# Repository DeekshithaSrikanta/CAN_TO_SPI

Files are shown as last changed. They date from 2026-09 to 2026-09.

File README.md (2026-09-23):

CAN to SPI Bridge (FPGA RTL)

 Overview

This repository contains a Verilog-based RTL architecture that bridges a Controller Area Network (CAN) bus to a Serial Peripheral Interface (SPI).
Designed and tested on the Intel DE10-Lite (MAX 10 - 10M50DAF484C7G) FPGA, this system ingests a 500 kbps serial CAN frame, validates the data (CRC and EOF), packages the identifier and payload into a 112-bit parallel register, and transmits it serially via an SPI Master interface.

System Architecture and Data Flow

The bridge operates through three distinct hardware phases:

1. CAN Frame Ingestion: The `can_controller` state machine parses the incoming serial CAN bitstream (500 kbps) via the `can_rx` pin. It actively calculates the CRC-15 and handles bit-stuffing logic.
2.Parallel Assembly: Upon successful End of Frame (EOF) validation, the parsed CAN ID, Data Length Code (DLC), and payload are packaged into a single 112-bit internal parallel register (`spi_rx_packet`).
3. SPI Transmission: Once the parallel packet is assembled, the SPI master activates the Chip Select (`cs_n`), pulses the SPI Clock (`sck`), and shifts the 112-bit payload out serially over the `mosi` pin.

## Module Breakdown

* `can_spi_master_top.v` - The top-level wrapper that connects the physical FPGA pins to the internal bridge logic.
* `can_controller.v` - The FSM that handles the CAN protocol parsing, idle state detection, CRC validation, and EOF checking.
* `can_generator.v` - An internal hardware bypass module. It acts as an on-chip test pattern generator that injects a pre-recorded, perfectly timed CAN frame directly into the controller, triggered by a physical slide switch.

Hardware Requirements

* Board: Terasic DE10-Lite (Intel MAX 10 FPGA)
* Target Device: 10M50DAF484C7G
* Clock: 50 MHz internal oscillator

Pin Assignments (DE10-Lite)

| Signal Name | FPGA Pin | Board Component / I/O Standard |
| --- | --- | --- |
| `clk_50mhz` | `PIN_P11` | 50 MHz MAX 10 Clock (3.3-V LVTTL) |
| `rst_n` | `PIN_B8` | KEY[0] Push Button (3.3-V LVTTL) |
| `can_rx` | `PIN_V10` | GPIO Expansion Header (3.3-V LVTTL) |
| `mosi` | `PIN_V9` | GPIO Expansion Header (3.3-V LVTTL) |
| `cs_n` | `PIN_W9` | GPIO Expansion Header (3.3-V LVTTL) |
| `sck` | `PIN_W10` | GPIO Expansion Header (3.3-V LVTTL) |
| `test_switch` | `PIN_C10` | SW[0] Slide Switch (Internal test trigger) |

 Simulation and Verification

This project has been verified using both RTL Simulation (for mathematical and state machine validation) and
Gate-Level Simulation (GLS) (for physical timing, synthesis mapping, and propagation delay validation).

2. Open Signal Tap and set the trigger to `cs_n` (Falling Edge).
3. Flick `SW[0]` on the board to activate the `can_generator.v` module.
4. The internal generator will feed a simulated 500 kbps CAN frame to the controller, allowing Signal Tap to capture the resulting SPI output on `mosi` and `sck`.

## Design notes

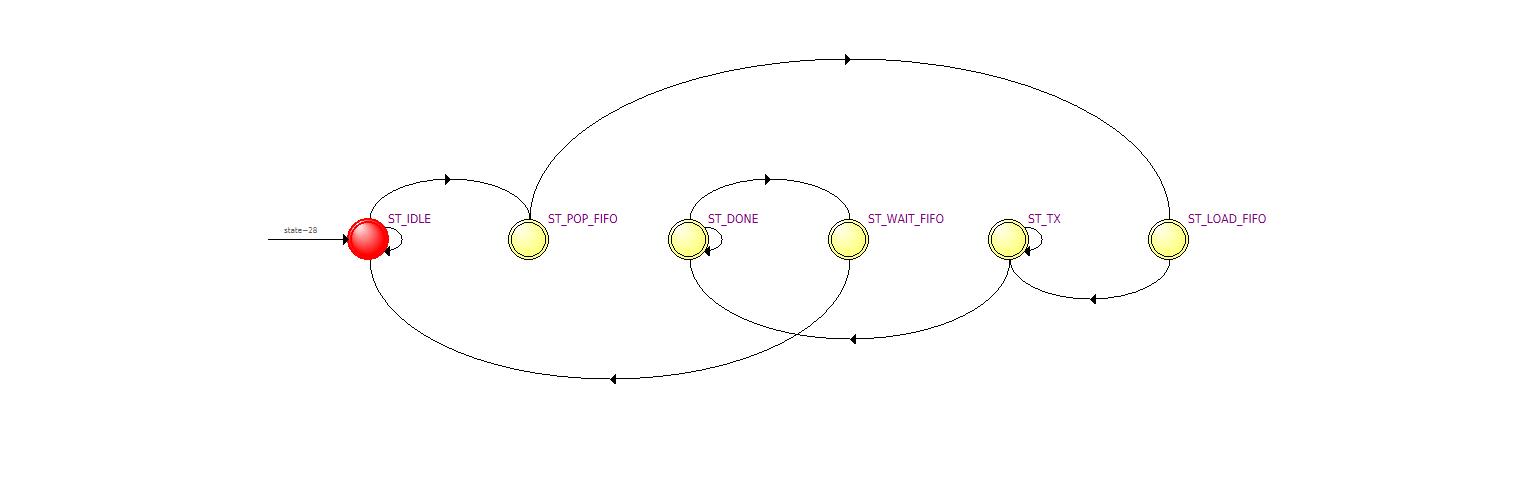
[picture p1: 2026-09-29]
state diagram.jpg

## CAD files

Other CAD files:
stp1.stp

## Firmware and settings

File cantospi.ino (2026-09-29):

#include <Arduino.h>
#include <string.h>
#include "driver/spi_slave.h"
#include "driver/spi_common.h"
#include "driver/twai.h"

// ---------- Active Pins ----------
#define CAN_TX_PIN GPIO_NUM_5
#define SPI_MOSI 13
#define SPI_SCLK 14
#define SPI_CS   15

// FPGA outputs a 112-bit packet (14 bytes)
#define SPI_PACKET_SIZE 14
WORD_ALIGNED_ATTR uint8_t spi_rx_buf[SPI_PACKET_SIZE];

void setup() {
  Serial.begin(115200);
  delay(1000);

  Serial.println("\nESP32 CAN Transmit + SPI Slave Test");

  // 1. Configure SPI Slave (Receive Only)
  spi_bus_config_t buscfg;
  memset(&buscfg, 0, sizeof(buscfg));
  buscfg.mosi_io_num = SPI_MOSI;
  buscfg.miso_io_num = -1;       // Completely disabled
  buscfg.sclk_io_num = SPI_SCLK;
  buscfg.quadwp_io_num = -1;
  buscfg.quadhd_io_num = -1;
  buscfg.max_transfer_sz = 32;

  spi_slave_interface_config_t slvcfg;
  memset(&slvcfg, 0, sizeof(slvcfg));
  slvcfg.spics_io_num = SPI_CS;
  slvcfg.queue_size = 1;
  slvcfg.mode = 0; 

  spi_slave_initialize(VSPI_HOST, &buscfg, &slvcfg, SPI_DMA_CH_AUTO);
  Serial.println("SPI Slave initialized on Pins 13, 14, 15.");

  // 2. Configure CAN (TWAI)
  twai_general_config_t g_config = TWAI_GENERAL_CONFIG_DEFAULT(CAN_TX_PIN, GPIO_NUM_4, TWAI_MODE_NO_ACK);
  twai_timing_config_t t_config = TWAI_TIMING_CONFIG_500KBITS();
  twai_filter_config_t f_config = TWAI_FILTER_CONFIG_ACCEPT_ALL();

  twai_driver_install(&g_config, &t_config, &f_config);
  twai_start();
  Serial.println("CAN Driver initialized on Pin 5.");

  Serial.println("\nType 's' in the serial monitor and press Enter to start.");
}

void loop() {
  if (Serial.available() > 0) {
    char incoming = Serial.read();
    if (incoming == 's' || incoming == 'S') {
      
      // A. Queue the SPI listener FIRST
      spi_slave_transaction_t t;
      memset(&t, 0, sizeof(t));
      t.length = SPI_PACKET_SIZE * 8; 
      t.rx_buffer = spi_rx_buf;
      t.tx_buffer = NULL; // Explicitly disabled
      
      spi_slave_queue_trans(VSPI_HOST, &t, portMAX_DELAY);

      // B. Transmit the CAN Frame
      twai_message_t message;
      message.identifier = 0x123;
      message.extd = 0;
      message.data_length_code = 8;
      uint8_t payload[8] = {0x11, 0x22, 0x33, 0x44, 0x55, 0x66, 0x77, 0x88};
      memcpy(message.data, payload, 8);

      if (twai_transmit(&message, pdMS_TO_TICKS(1000)) == ESP_OK) {
        Serial.println("\n-> CAN Sent (ID: 0x123). Waiting for SPI reply...");
      }

      // C. Wait for the SPI transaction from the FPGA to complete (2-second timeout)
      spi_slave_transaction_t *completed = nullptr;
      esp_err_t result = spi_slave_get_trans_result(VSPI_HOST, &completed, pdMS_TO_TICKS(2000));

      if (result == ESP_OK) {
        Serial.print("<- SUCCESS: Received 14 bytes from FPGA: ");
        for (int i = 0; i < SPI_PACKET_SIZE; i++) {
          Serial.printf("%02X ", spi_rx_buf[i]);
        }
        Serial.println();
        
        if (spi_rx_buf[0] == 0xAA && spi_rx_buf[12] == 0x55 && spi_rx_buf[13] == 0x55) {
          Serial.println("<- VERIFIED: Packet headers and footers match perfectly!");
        }
      } else {
        Serial.printf("<- ERROR: SPI Receive Timed Out (Code: %d).\n", result);
      }
    }
  }
}

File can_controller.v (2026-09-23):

`timescale 1ns / 1ps

module can_controller (
    input  wire        clk_50mhz,
    input  wire        rst_n,
    input  wire        rxd,
    
    output reg         frame_valid,
    output reg  [10:0] id,
    output reg  [3:0]  dlc,
    output wire [63:0] data,
    output reg         frame_error
);

    // -------------------------------------------------------------------------
    // State Machine Parameters (Moved to top for global scope visibility)
    // -------------------------------------------------------------------------
    localparam ST_IDLE      = 4'd0;
    localparam ST_ID        = 4'd1;
    localparam ST_RTR       = 4'd2;
    localparam ST_IDE       = 4'd3;
    localparam ST_R0        = 4'd4;
    localparam ST_DLC       = 4'd5;
    localparam ST_DATA      = 4'd6;
    localparam ST_CRC       = 4'd7;
    localparam ST_CRC_DELIM = 4'd8;
    localparam ST_EOF_WAIT  = 4'd9;

    reg [3:0] state;

    // -------------------------------------------------------------------------
    // 1. Bit Timing Unit (Synchronization & Oversampling)
    // -------------------------------------------------------------------------
    reg rxd_sync1, rxd_sync2, rxd_sync2_d;
    always @(posedge clk_50mhz or negedge rst_n) begin
        if (!rst_n) begin
            rxd_sync1   <= 1'b1;
            rxd_sync2   <= 1'b1;
            rxd_sync2_d <= 1'b1;
        end else begin
            rxd_sync1   <= rxd;
            rxd_sync2   <= rxd_sync1;
            rxd_sync2_d <= rxd_sync2;
        end
    end
    
    wire falling_edge = !rxd_sync2 && rxd_sync2_d;
    reg [2:0] prescaler;
    reg [4:0] tq_count;
    
    wire tq_tick = (prescaler == 3'd4);
    wire sample_enable = (tq_tick && tq_count == 5'd15); 
    
    // Updated to use the clean parameter name
    wire is_idle = (state == ST_IDLE); 
    
    always @(posedge clk_50mhz or negedge rst_n) begin
        if (!rst_n) begin
            prescaler <= 3'd0;
            tq_count  <= 5'd1;
        end else begin
            if (falling_edge && is_idle) begin 
                prescaler <= 3'd0;
                tq_count  <= 5'd1;
            end else if (tq_tick) begin
                prescaler <= 3'd0;
                if (tq_count == 5'd20) tq_count <= 5'd1;
                else tq_count <= tq_count + 5'd1;
            end else begin
                prescaler <= prescaler + 3'd1;
            end
        end
    end

    // -------------------------------------------------------------------------
    // 2. Destuffer
    // -------------------------------------------------------------------------
    reg [2:0] consec_cnt;
    reg       prev_bit;
    reg       destuffed_bit;
    reg       valid_bit_en;
    reg       stuff_err_flag;
    
    // Destuffing active from ST_ID to ST_CRC
    wire destuff_en = (state >= ST_ID && state <= ST_CRC); 

    always @(posedge clk_50mhz or negedge rst_n) begin
        if (!rst_n) begin
            consec_cnt     <= 3'd1;
            prev_bit       <= 1'b1;
            valid_bit_en   <= 1'b0;
            stuff_err_flag <= 1'b0;
            destuffed_bit  <= 1'b1;
        end else begin
            valid_bit_en   <= 1'b0;
            stuff_err_flag <= 1'b0;

            if (sample_enable) begin
                if (!destuff_en) begin
                    consec_cnt    <= 3'd1;
                    prev_bit      <= rxd_sync2;
                    destuffed_bit <= rxd_sync2;
                    valid_bit_en  <= 1'b1;
                end else begin
                    if (consec_cnt == 3'd5) begin
                        if (rxd_sync2 == prev_bit) stuff_err_flag <= 1'b1;
                        consec_cnt <= 3'd1;
                        prev_bit   <= rxd_sync2;
                    end else begin
                        if (rxd_sync2 == prev_bit) consec_cnt <= consec_cnt + 3'd1;
                        else consec_cnt <= 3'd1;
                        
                        prev_bit      <= rxd_sync2;
                        destuffed_bit <= rxd_sync2;
                        valid_bit_en  <= 1'b1;
                    end
                end
            end
        end
    end

    // -------------------------------------------------------------------------
    // 3. CRC-15 LFSR (Polynomial: x^15 + x^14 + x^10 + x^8 + x^7 + x^4 + x^3 + 1)
    // -------------------------------------------------------------------------
    reg [14:0] calc_crc;
    reg [14:0] rx_crc;
    
    // CRC accumulates from ST_ID through ST_DATA
    wire crc_enable = (state >= ST_ID && state <= ST_DATA); 
    
    wire crc_feedback = calc_crc[14] ^ destuffed_bit;
    wire [14:0] next_crc = {calc_crc[13:0], 1'b0} ^ (crc_feedback ? 15'h4599 : 15'h0000);

    always @(posedge clk_50mhz or negedge rst_n) begin
        if (!rst_n) calc_crc <= 15'd0;
        else if (valid_bit_en) begin
            if (state == ST_IDLE) calc_crc <= 15'd0; // Reset at SOF
            else if (crc_enable) calc_crc <= next_crc;
        end
    end

    // -------------------------------------------------------------------------
    // 4. Protocol Engine FSM
    // -------------------------------------------------------------------------
    reg [6:0] bit_cnt;
    reg [63:0] data_reg;
    reg rtr_bit;

    assign data = (dlc == 0) ? 64'h0 : (data_reg << ((8 - dlc) * 8));
    wire [3:0] next_dlc = {dlc[2:0], destuffed_bit};

    always @(posedge clk_50mhz or negedge rst_n) begin
        if (!rst_n) begin
            state       <= ST_IDLE;
            bit_cnt     <= 7'd0;
            id          <= 11'd0;
            dlc         <= 4'd0;
            data_reg    <= 64'd0;
            rx_crc      <= 15'd0;
            frame_valid <= 1'b0;
            frame_error <= 1'b0;
            rtr_bit     <= 1'b0;
        end else begin
            frame_valid <= 1'b0;
            frame_error <= 1'b0;
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
